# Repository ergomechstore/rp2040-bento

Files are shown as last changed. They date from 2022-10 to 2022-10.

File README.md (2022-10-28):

# RP2040-Bento

The RP2040-bento is a breakout board for the RP2040 MCU.

The board doesn't have onboard USB port so the USB port should be designed into the carrier board.

The Fabrication files are available, these files has been tested with jlcpcb service with greate success.

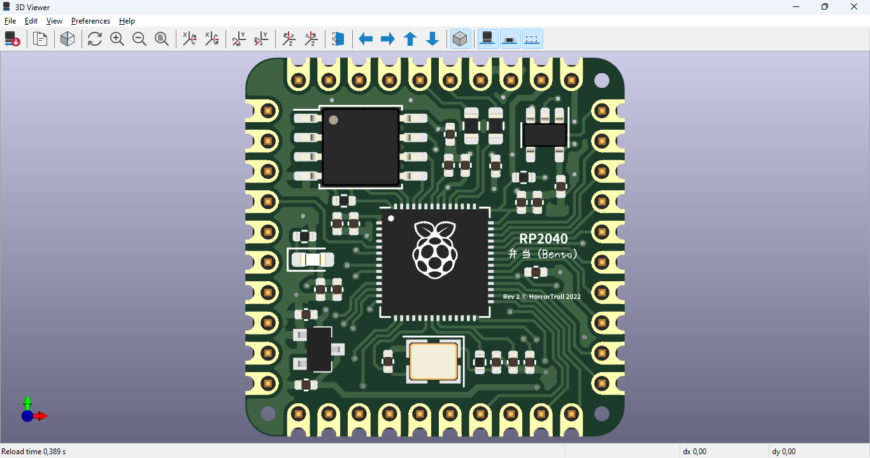
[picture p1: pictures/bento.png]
Breakout board

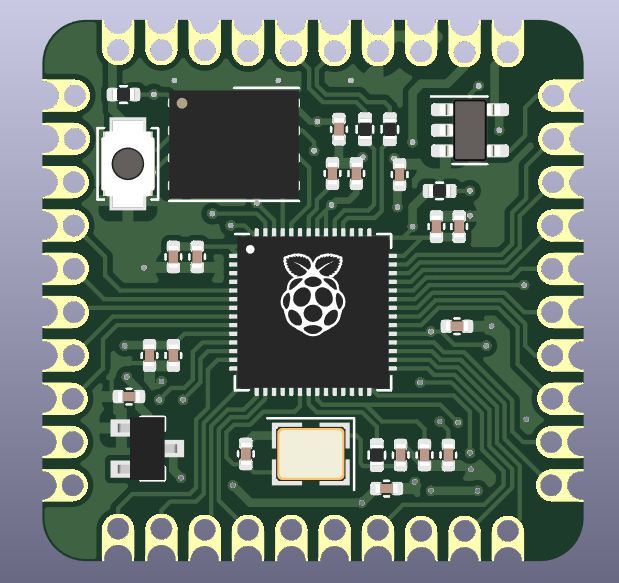
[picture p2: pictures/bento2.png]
Bento board

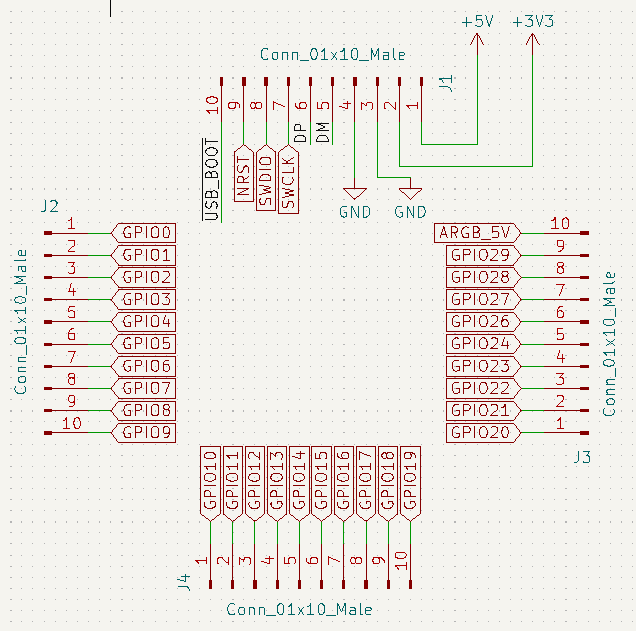
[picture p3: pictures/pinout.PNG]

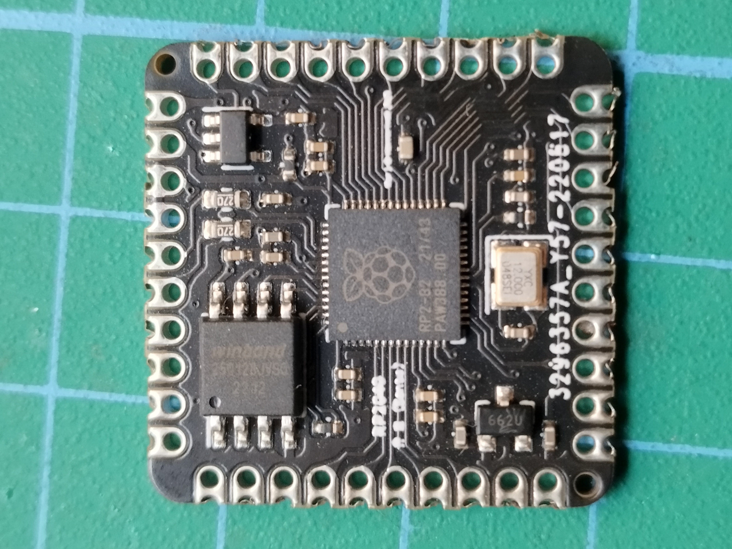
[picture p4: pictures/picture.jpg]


This is still in development, though initial testing has been done, the design is still not in its final shape, please consider carefully before ordering from JLCPCB. You might need to do some debugging if problems arise.

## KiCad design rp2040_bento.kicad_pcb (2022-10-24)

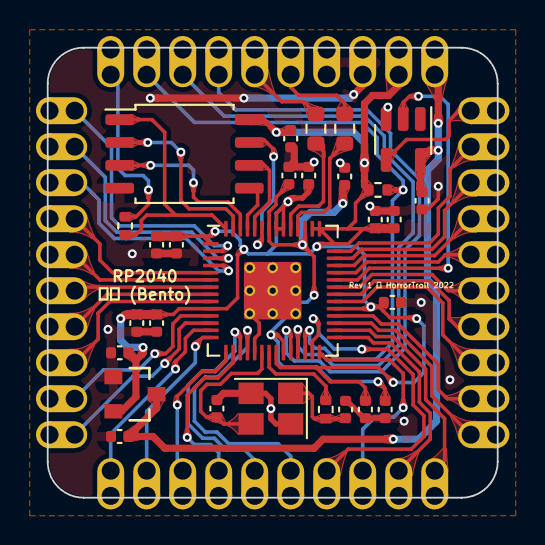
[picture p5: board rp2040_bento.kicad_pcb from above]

Board: 2 copper layers, 25.0 x 25.0 mm, 32 parts (0 on the bottom side), 52 nets.

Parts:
C1: 10u; C_0402_1005Metric
C2, C3, C4, C5, C6, C7, C8, C9, C10, C15, C18: 100n; C_0402_1005Metric
C11, C12, C16, C17: 1u; C_0402_1005Metric
C13, C14: 22p; C_0402_1005Metric
J1, J2, J3, J4: Conn_01x10_Male; Pinouts_Castellated_Oval_01x10
R1: 10K; R_0402_1005Metric
R2, R3: 1K; R_0402_1005Metric
R6, R7: 27R; R_0603_1608Metric
RG1: XC6206P332MR; Torex-XC6206P332MR
U1: RP2040; RP2040-QFN-56
U2: W25Q128JVSIQ; SOIC-8_5.23x5.23mm_P1.27mm
U3: 74LVC1G17; SOT-23-5
Y1: 12Mhz; Crystal_SMD_3225-4Pin_3.2x2.5mm

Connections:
+1V1: C9.1, C10.1, C12.1, U1.23 (DVDD), U1.45 (VREG_VOUT), U1.50 (DVDD)
+3V3: C1.1, C2.1, C3.1, C4.1, C5.1, C6.1, C7.1, C8.1, C11.1, C15.1, C17.1, J1.2, R1.1, RG1.2 (VOUT), U1.1 (IOVDD), U1.10 (IOVDD), U1.22 (IOVDD), U1.33 (IOVDD), U1.42 (IOVDD), U1.43 (ADC_AVDD), U1.44 (VREG_VIN), U1.48 (USB_VDD), U1.49 (IOVDD), U2.8 (VCC)
+5V: C16.1, C18.1, J1.1, RG1.3 (VIN), U3.5
/DM: J1.5, R7.2
/DP: J1.6, R6.2
/~USB_BOOT: J1.10, R3.1
ARGB_3V3: U1.37 (GPIO25), U3.2
ARGB_5V: J3.10, U3.4
D+: R6.1, U1.47 (D+)
D-: R7.1, U1.46 (D-)
FLASH_SCK: U1.52 (QSPI_SCLK), U2.6 (CLK)
FLASH_SD0: U1.53 (QSPI_SD0), U2.5 (DI(IO0))
FLASH_SD1: U1.55 (QSPI_SD1), U2.2 (DO(IO1))
FLASH_SD2: U1.54 (QSPI_SD2), U2.3 (IO2)
FLASH_SD3: U1.51 (QSPI_SD3), U2.7 (IO3)
FLASH_nCS: R3.2, U1.56 (QSPI_SS_N), U2.1 (~CS)
GND: C1.2, C2.2, C3.2, C4.2, C5.2, C6.2, C7.2, C8.2, C9.2, C10.2, C11.2, C12.2, C13.2, C14.2, C15.2, C16.2, C17.2, C18.2, J1.3, J1.4, RG1.1 (VSS), U1.19 (TESTEN), U1.57 (GND), U2.4 (GND), U3.3, Y1.2, Y1.4
GPIO0: J2.1, U1.2 (GPIO0)
GPIO1: J2.2, U1.3 (GPIO1)
GPIO2: J2.3, U1.4 (GPIO2)
GPIO3: J2.4, U1.5 (GPIO3)
GPIO4: J2.5, U1.6 (GPIO4)
GPIO5: J2.6, U1.7 (GPIO5)
GPIO6: J2.7, U1.8 (GPIO6)
GPIO7: J2.8, U1.9 (GPIO7)
GPIO8: J2.9, U1.11 (GPIO8)
GPIO9: J2.10, U1.12 (GPIO9)
GPIO10: J4.1, U1.13 (GPIO10)
GPIO11: J4.2, U1.14 (GPIO11)
GPIO12: J4.3, U1.15 (GPIO12)
GPIO13: J4.4, U1.16 (GPIO13)
GPIO14: J4.5, U1.17 (GPIO14)
GPIO15: J4.6, U1.18 (GPIO15)
GPIO16: J4.7, U1.27 (GPIO16)
GPIO17: J4.8, U1.28 (GPIO17)
GPIO18: J4.9, U1.29 (GPIO18)
GPIO19: J4.10, U1.30 (GPIO19)
GPIO20: J3.1, U1.31 (GPIO20)
GPIO21: J3.2, U1.32 (GPIO21)
GPIO22: J3.3, U1.34 (GPIO22)
GPIO23: J3.4, U1.35 (GPIO23)
GPIO24: J3.5, U1.36 (GPIO24)
GPIO26: J3.6, U1.38 (GPIO26/ADC0)
GPIO27: J3.7, U1.39 (GPIO27/ADC1)
GPIO28: J3.8, U1.40 (GPIO28/ADC2)
GPIO29: J3.9, U1.41 (GPIO29/ADC3)
unnamed: C14.1, R2.2, Y1.1
SWCLK: J1.7, U1.24 (SWCLK)
SWDIO: J1.8, U1.25 (SWDIO)
XTAL1: C13.1, U1.20 (XTAL_IN), Y1.3
XTAL2: R2.1, U1.21 (XTAL_OUT)
~NRST: J1.9, R1.2, U1.26 (~RUN)

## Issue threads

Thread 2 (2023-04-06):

No records on pick-and-place

ManoShu, 2023-04-06:
Hello, I am very interested in testing this board however, as the title suggests, the release contain an empty position file.
By it's name, it seems that the component barren bottom side file was uploaded instead of the top one.
As I am currently unable to use Kicad to generate it myself, it would be nice to have the file readily available to order prototype units.

Thanks in advance.

ManoShu, 2023-09-01:
Just letting anyone arriving at this issue that the ordered board work successfully.

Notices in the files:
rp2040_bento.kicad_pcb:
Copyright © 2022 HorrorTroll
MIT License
